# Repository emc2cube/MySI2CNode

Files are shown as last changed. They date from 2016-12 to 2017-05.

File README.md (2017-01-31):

MySI2CNode
==========

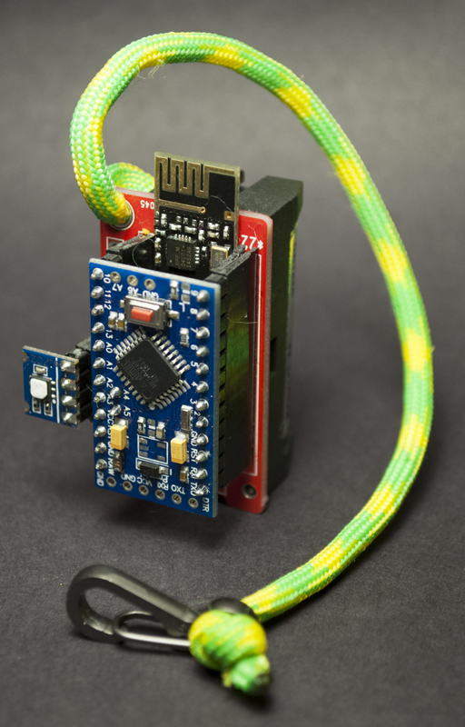
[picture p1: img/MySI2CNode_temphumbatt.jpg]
Node with battery and Si7021

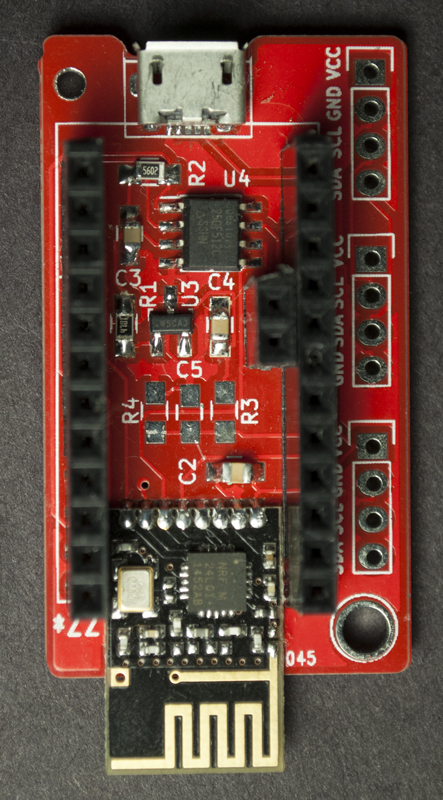
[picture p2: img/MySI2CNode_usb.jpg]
Node with micro USB

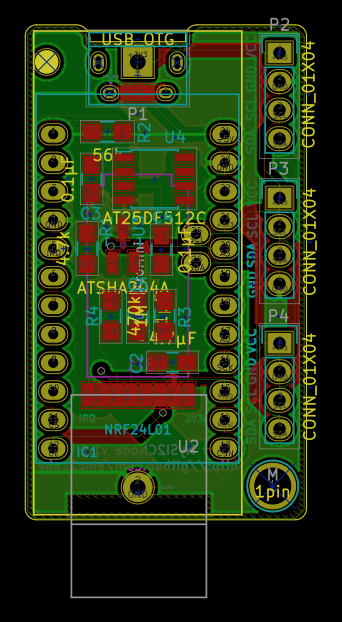
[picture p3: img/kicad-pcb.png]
KiCad view


Description
-----------

Simple [MySensors](http://www.mysensors.org) sensor node with support for up to 3 I2C modules (nRF24L01, 2.4GHz).

Ordering
--------

Gerber files are included so you can order these PCB at your favorite PCB fab house and solder the few components yourself.
For an easy ordering process you can directly order these PCB without having to do anything else:
- [PCBs.io](https://PCBs.io/share/8VvDe) 4 for $6.78, black 1.2mm PCB, ENIG finish.
- [DirtyPCBs](http://dirtypcbs.com/store/designer/details/10880/1157/mysi2cnode-zip) ~10 for $15.95, multiple colors and PCB thickness, HASL finish.

Assembly
--------

If you plan to power this node by a battery it is advised to first prepare your arduino pro mini according to [MySensors battery powered sensors specifications](https://www.mysensors.org/build/battery) (removing Vreg and power indicator LED). You may also want to change your BOD fuse settings.
Do not remove the voltage regulator if you are powering the sensors using a USB wall charger, it will be used to power both arduino and radio module.

If you are using a battery holder start by soldering all SMD components except the radio module. Continue with arduino pin headers, trim them as close as you can of the PCB.
Then solder the battery holder and if you need trim the negative pin to be flush with the PCB. Finally you can carefully add the radio module.

Optional components
-------------------

### Dual power mode
You can run this node using batteries, a CR123 battery holder can be mounted on the PCB, using + and - pins of the PCB.
It is also designed to use a micro USB connector as power input, any old USB phone charger will do.

### Battery monitoring
If using a battery to power the sensor current battery level can be sent to the controller if R3, R4 and C5 are installed.

### ATSHA204 module
For security reason you can add a CryptAuthEE SHA256 chip. This will allow you to sign messages and will secure communications between the node and your gateway (this is not encryption, just signing).
If you only control lights, fan, or other non-essential hardware you probably don't need to bother with this chip.
Signing can also be done at the software level, without the chip if you decide to add this function later.

### Eeprom module
This module is only used to perform OTA updates on the node. If you don't plan to use this feature you can also skip this chip.
You will also need to burn a compatible bootloader to your arduino (DualOptiBoot)

Arduino
-------

Included program(s)

### MySI2CNode-SI7021_TempHum
Use "i2c_SI7021.h" library from [I2C-Sensor-Lib (iLib)](https://github.com/orgua/iLib).
Simple program to retrieve temperature and humidity. Will also check battery status and report to controller.

Revision history
----------------

Version 1.0: Initial release.

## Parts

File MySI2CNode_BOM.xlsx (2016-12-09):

Quantity | Reference | Value | Package | Manufacturer | Manufacturer P/N | Mouser P/N | Comment | Aliexpress or Ebay link
1 | P1 | USB_OTG | Micro USB connector | Hirose Connector | ZX62D-B-5PA8(30) | 798-ZX62D-B-5PA830 |  | https://www.aliexpress.com/item/Free-Shipping-100pcs-Micro-USB-5P-5-pin-Micro-USB-Jack-5Pins-Micro-USB-Connector-Tail/32307359968.html
1 | BT1 | Battery | CR123 battery holder | Keystone Electronics | 1051 | 534-1051 |  | https://www.aliexpress.com/item/CR123A-CR123-Lithium-Battery-Holder-Box-Clip-Case-w-PCB-Mounting-Lead-6Pcs/32739137115.html
1 | IC1 | ArduinoProMini | Arduino Pro Mini 3.3V 8MHz | Arduino | Pro Mini 3.3V |  |  | https://www.aliexpress.com/item/10pcs-lot-Pro-Mini-328-Mini-3-3V-8M-ATMEGA328-ATMEGA328P-AU-3-3V-8MHz-for/1966734488.html
1 | U2 | NRF24L01 | NRF24L01-SMD radio module | Radio module | NRF24L01+ SMD |  |  | https://www.aliexpress.com/item/5pcs-Free-Shipping-NRF24l01-2-4GHz-Wireless-Module-Mini-Version/32430542898.html
1 | U3 | ATSHA204A | SOT-23 | Atmel | ATSHA204A-STUCZ-T | 566-ATSHA204ASTUCZ-T | Optional, for signing
1 | U4 | AT25DF512C | SOIC-8 | Adesto Technologies | AT25DF512C-SSHN-B | 988-AT25DF512CSSHN-B | Optional, for OTA
1 | C2 | 4.7µF | SMD 0805 | Murata | GRM21BR61C475KA88K | 81-GRM21BR61C475KA8K |  | http://www.aliexpress.com/item/1LOT-100PCS-Chip-Capacitors-4-7uF-475K-16V-10-0805-Package0805-2012-Metric/32561376020.html
3 | C3-5 | 0.1µF | SMD 0805 | Murata | GRM21R71C104JA01D | 81-GRM21R71C104JA01D |  | http://www.aliexpress.com/item/1LOT-100PCS-Chip-Capacitors-0-1uF-104K-16V-10-0805-Package0805-2012-Metric/32560085454.html
1 | R1 | 4.7k | SMD 0805 | Bourns | CR0805-JW-472ELF | 652-CR0805-JW-472ELF |  | http://www.aliexpress.com/item/100pcs-lot-SMD-Chip-Resistor-1-0805-4-7K-4700-OHMS-1-8W-100-YAGEO-New/32570155447.html
1 | R2 | 56k | SMD 0805 | Bourns | CR0805-JW-563ELF | 652-CR0805JW-563ELF |  | http://www.aliexpress.com/item/100pcs-lot-SMD-Chip-Resistor-1-0805-56K-1-8W-100-YAGEO-New-Original-Chip-Fixed/32570183133.html
1 | R3 | 1M | SMD 0805 | Bourns | CR0805-JW-105ELF | 652-CR0805JW-105ELF |  | https://www.aliexpress.com/item/100pcs-lot-SMD-Chip-Resistor-1-0805-1M-1-8W-100-YAGEO-New-Original-Chip-Fixed/32569356535.html
1 | R4 | 470k | SMD 0805 | Bourns | CR0805-JW-474ELF | 652-CR0805JW-474ELF |  | https://www.aliexpress.com/item/100pcs-lot-SMD-Chip-Resistor-1-0805-470K-1-8W-100-YAGEO-New-Original-Chip-Fixed/32569352634.html

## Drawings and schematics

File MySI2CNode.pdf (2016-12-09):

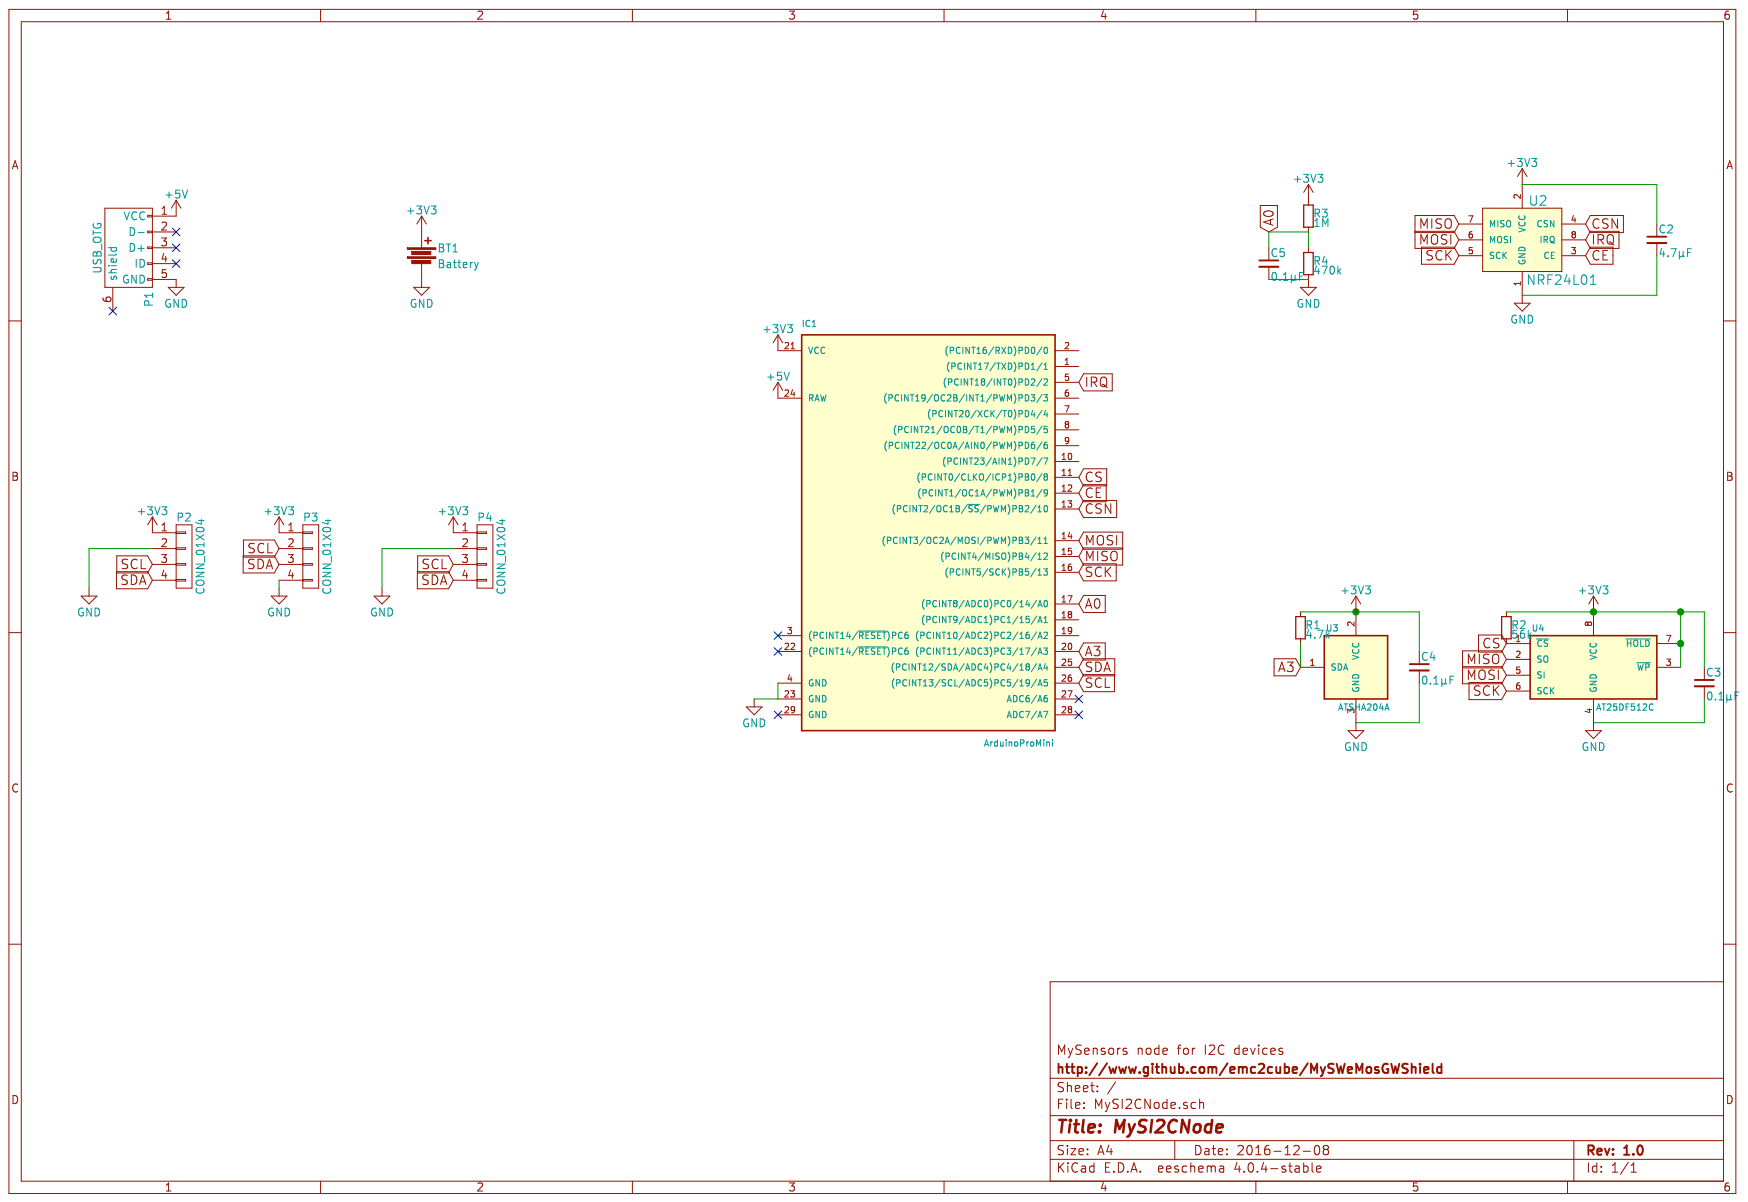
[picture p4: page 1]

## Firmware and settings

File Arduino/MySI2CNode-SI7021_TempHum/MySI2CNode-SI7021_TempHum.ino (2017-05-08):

/**
   The MySensors Arduino library handles the wireless radio link and protocol
   between your home built sensors/actuators and HA controller of choice.
   The sensors forms a self healing radio network with optional repeaters. Each
   repeater and gateway builds a routing tables in EEPROM which keeps track of the
   network topology allowing messages to be routed to nodes.

   Created by Henrik Ekblad <henrik.ekblad@mysensors.org>
   Copyright (C) 2013-2015 Sensnology AB
   Full contributor list: https://github.com/mysensors/Arduino/graphs/contributors

   Documentation: http://www.mysensors.org
   Support Forum: http://forum.mysensors.org

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
 *******************************

   REVISION HISTORY
   Version 1.0 - Henrik EKblad

   DESCRIPTION
   This sketch provides an example how to implement a humidity/temperature
   sensor using a Si7021 I2C module
   http://www.mysensors.org/build/humidity
*/

// Customize your device name.
String Location = "Plants";     // Location of the device, will be sent to the gateway with each device

// Enable debug prints
//#define MY_DEBUG

// Enable and select radio type attached
#define MY_RADIO_NRF24

// Wait a few ms between radio Tx
#define MESSAGEWAIT 500

#define MY_NODE_ID AUTO
//#define MY_PARENT_NODE_ID 0

#define BATTERY_MONITORING                  // Enable battery monitoring

// possible values: RF24_PA_LOW (is default on gateway), RF24_PA_MED, RF24_PA_HIGH, RF24_PA_MAX (is default on nodes)
//#define MY_RF24_PA_LEVEL RF24_PA_LOW      // Enable to save battery if sensor not too far from gateway. Probably not worth it.

// RF channel for the sensor net, 0-127. Channel 76 is the default in all library examples
//#define MY_RF24_CHANNEL     76

//RF24_250KBPS for 250kbs (default), RF24_1MBPS for 1Mbps, or RF24_2MBPS for 2Mbps
//#define MY_RF24_DATARATE      RF24_250KBPS

// Set this to true if you want to send values altough the values did not change.
// This is only recommended when not running on batteries.
const bool SEND_ALWAYS = false;

#include <SPI.h>
#include <MySensors.h>
#include <Wire.h>
#include "i2c_SI7021.h"
SI7021 si7021;

#define CHILD_ID_HUM 0
#define CHILD_ID_TEMP 1

#if defined MY_DEBUG
const unsigned long SLEEP_TIME = 15000UL; // If debug, TX every 15s
#else
const unsigned long SLEEP_TIME = 1800000UL; // Sleep time between reads (in milliseconds), 30min
#endif
float lastTemp, lastHum;
boolean metric = true;
MyMessage msgHum(CHILD_ID_HUM, V_HUM);
MyMessage msgTemp(CHILD_ID_TEMP, V_TEMP);

#if defined BATTERY_MONITORING
int BATTERY_SENSE_PIN = A0;  // select the input pin for the battery sense point
int oldBatteryPcnt = 0;
#endif // end BATTERY_MONITORING

#define SN "Temperature Humidity node"  // Name of the sketch
#define SV "2.1.1"                      // Version (2.x : use MySensors 2.x)

void setup() {
  if (!si7021.initialize()) {
    Serial.println("Can't find SI7021 sensor!");
    while (1) {};
  }
  // use the 1.1 V internal reference
#if defined(__AVR_ATmega2560__)
  analogReference(INTERNAL1V1);
#else
  analogReference(INTERNAL);
#endif
  metric = getControllerConfig().isMetric;  // was getConfig().isMetric; before MySensors v2.1.1
  Serial.println("Mobile Temperature and Humidity sensor node ready.");
}

void presentation()
{
  // Send the Sketch Version Information to the Gateway
  sleep(MESSAGEWAIT);
  sendSketchInfo(SN, SV);

  // Register all sensors to gw (they will be created as child devices)
  String humReg = Location + " Hum";
  sleep(MESSAGEWAIT);
  present(CHILD_ID_HUM, S_HUM, humReg.c_str());
  String tempReg = Location + " Temp";
  sleep(MESSAGEWAIT);
  present(CHILD_ID_TEMP, S_TEMP, tempReg.c_str());
}

void loop()
{
  // Fetch temperature from sensor
  float temperature;
  si7021.getTemperature(temperature);
  temperature = round(temperature * 10) / 10.0; // 0.1°C accuracy is sensistive enough
  if (SEND_ALWAYS || temperature != lastTemp) {
    lastTemp = temperature;
    if (!metric) {
      temperature = temperature * 9.0 / 5.0 + 32.0;
    }
    wait(MESSAGEWAIT);
    send(msgTemp.set(temperature, 1));
#if defined MY_DEBUG
    Serial.print(F("Temperature: "));
    Serial.print(temperature);
    Serial.println(metric ? F(" °C") : F(" °F"));
#endif
  }

  // Fetch humidity from sensor
  float humidity;
  si7021.getHumidity(humidity);
  humidity = round(humidity); // 1% RH accuracy is sensistive enough
  // Clip humidity values to a valid range
  // If sent RH > 100% domoticz will ignore both temperature and humidity readings
  humidity = humidity > 100 ? 100 : humidity;
  humidity = humidity < 0   ? 0   : humidity;
  if (SEND_ALWAYS || humidity != lastHum) {
    lastHum = humidity;
    wait(MESSAGEWAIT);
    send(msgHum.set(humidity, 0));
#if defined MY_DEBUG
    Serial.print(F("Humidity: "));
    Serial.print(humidity);
    Serial.println(F(" %"));
#endif
  }

#if defined BATTERY_MONITORING
  // get the battery Voltage
  int sensorValue = analogRead(BATTERY_SENSE_PIN);
#ifdef MY_DEBUG
  Serial.print(F("Battery voltage ADC: "));
  Serial.println(sensorValue);
#endif
  // 1M, 470K divider across battery and using internal ADC ref of 1.1V
  // Sense point is bypassed with 0.1 uF cap to reduce noise at that point
  // ((1e6+470e3)/470e3)*1.1 = Vmax = 3.44 Volts
  // 3.44/1023 = Volts per bit = 0.003363075
  int batteryPcnt = sensorValue / 10;
#ifdef MY_DEBUG
  float batteryV  = sensorValue * 0.003363075;
  Serial.print("Battery Voltage: ");
  Serial.print(batteryV);
  Serial.println(" V");
  Serial.print("Battery percent: ");
  Serial.print(batteryPcnt);
  Serial.println(" %");
#endif
  if (abs(batteryPcnt - oldBatteryPcnt) <= 1) {
    batteryPcnt = oldBatteryPcnt;
  }
  if (oldBatteryPcnt != batteryPcnt) {
    wait(MESSAGEWAIT);
    sendBatteryLevel(batteryPcnt);
    oldBatteryPcnt = batteryPcnt;
  }
#endif // end BATTERY_MONITORING

  sleep(SLEEP_TIME); //sleep a bit

}

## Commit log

2016-12-09 Initial release
    Initial release
    [MySI2CNode-B.Cu.gbl, MySI2CNode-B.Mask.gbs, MySI2CNode-B.SilkS.gbo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]
2016-12-09 BOM
    Added BOM
    [MySI2CNode_BOM.xlsx]
2017-01-16 Arduino code fix
    Corrected compilation error with SLEEP_TIME while in MY_DEBUG mode.
    [MySI2CNode-SI7021_TempHum.ino]

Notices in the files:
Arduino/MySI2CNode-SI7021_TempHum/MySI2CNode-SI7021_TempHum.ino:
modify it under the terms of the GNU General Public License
